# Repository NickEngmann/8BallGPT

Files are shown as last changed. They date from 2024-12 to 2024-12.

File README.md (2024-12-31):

# Magic (GPT)8 Ball 🎱

## Overview

The Magic (GPT)8 Ball is a modern reinvention of the classic fortune-telling toy, powered by AI and IoT technology. It features voice recognition, motion sensing, and real-time AI responses through ChatGPT. When shaken, it records your question through a built-in microphone, processes it using OpenAI's APIs, and displays a mystical response on its integrated circular display.

## Features

- Voice-activated recording with automatic silence detection
- Motion-based activation using QMI8658 6-axis IMU
- Real-time transcription using OpenAI's Whisper API
- AI-powered responses from ChatGPT
- Smooth animations and UI transitions
- RGB LED status indicator
- Haptic feedback through dual vibration motors
- WiFi manager for easy network setup
- Offline mode with classic Magic 8 Ball responses
- Built-in battery management and charging

## Hardware Requirements

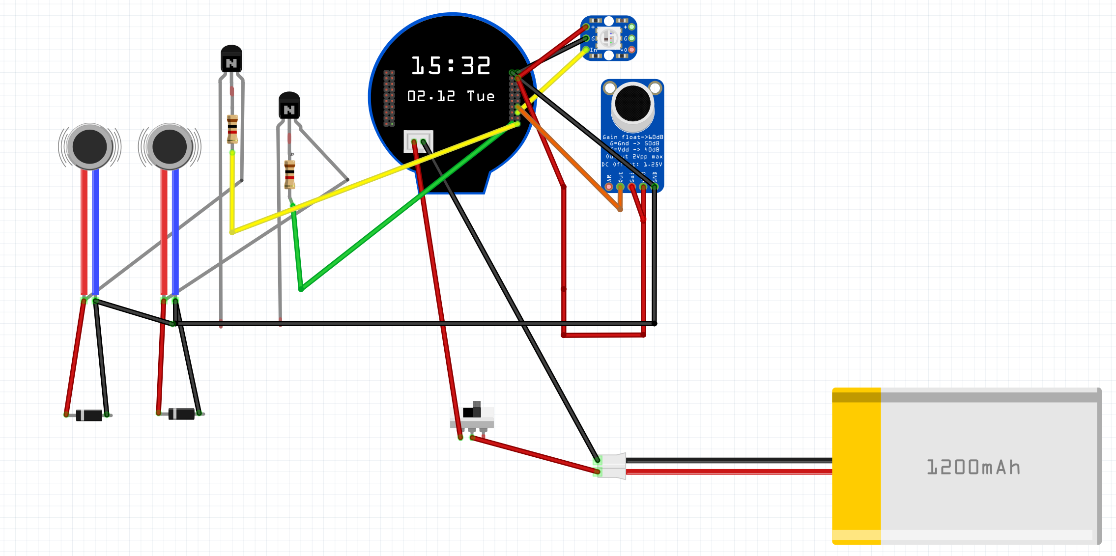
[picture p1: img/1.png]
Project Wiring Diagram


### Core Components

- Waveshare ESP32-S3 1.28" LCD Development Board
  - ESP32-S3 microcontroller
  - 1.28" Round LCD Display (240×240 resolution)
  - Built-in QMI8658 6-axis IMU
  - USB-C for programming and charging
- MAX9814 Microphone Amplifier Module
- 2x Vibration Motors
- WS2812B RGB LED
- 1200mAh LiPo Battery
- 3D printed enclosure (files TBD)

### Pin Connections

#### Built-in Components (ESP32-S3 Board)

- LCD Display
  - DC: GPIO8
  - CS: GPIO9
  - CLK: GPIO10
  - MOSI: GPIO11
  - RST: GPIO12
  - BL: GPIO40
- QMI8658 IMU
  - SDA: GPIO6
  - SCL: GPIO7

#### External Components

- MAX9814 Microphone
  - VDD → 3.3V
  - GND → GND
  - OUT → GPIO2 (ADC1_CH1)
- Vibration Motors
  - Motor 1: GPIO5
  - Motor 2: GPIO13
- RGB LED: GPIO3

## Software Setup

### Development Environment

1. Install Visual Studio Code
2. Install PlatformIO IDE extension
3. Clone the repository:

   ```bash
   git clone https://github.com/NickEngmann/MagicGPT8Ball.git
   cd MagicGPT8Ball
   ```

### Dependencies

- WiFiManager for network configuration
- ArduinoJson (7.x) for API communication
- LVGL for UI and animations
- TFT_eSPI for display driver
- Adafruit_NeoPixel for RGB LED control

### APIs and Services

1. Set up a val.town account:
   - Deploy the included `val.town.js` function
   - Update the endpoint URL in `main.cpp`
2. Configure OpenAI API key in val.town environment

### Building and Flashing

1. Open project in VS Code with PlatformIO
2. Install dependencies:

   ```bash
   pio lib install
   ```

3. Build and upload:

   ```bash
   pio run --target upload
   ```

### Environment Configuration

1. In the project root directory, create a `.env` file with your val.town endpoint and device token:

   ```ini
   VALTOWN_URL="https://your-valtown-endpoint.val.run"
   DEVICE_TOKEN="your-device-token"
   ```

2. For reference, an `.env.example` file is provided:

   ```ini
   VALTOWN_URL="https://example-valtown-endpoint.val.run"
   DEVICE_TOKEN="example-device-token"
   ```

   **Note:** Never commit your actual `.env` file to version control. The `.env.example` file serves as a template.

3. File locations should follow this structure:

   ```
   MagicGPT8Ball/
   ├── .env                  # Your actual configuration (do not commit)
   ├── .env.example         # Template for others (safe to commit)
   ├── generate_env.py      # Handles environment setup
   ├── data/                # Generated during build
   └── ...
   ```

4. During build:
   - The system automatically copies your `.env` file to the device's filesystem
   - If `.env` is missing, it will use `.env.example` as a fallback
   - Environment variables are securely stored on the device

5. To update configuration:
   - Modify `.env` file
   - Rebuild and upload filesystem:

     ```bash
     pio run -t uploadfs
     ```

   - Upload program:

     ```bash
     pio run -t upload
     ```

## Usage Instructions

### First-Time Setup

1. Power on the device
2. Connect to "MagicGPT8Ball" WiFi network
3. Configure your WiFi through the captive portal
4. Device will restart and connect to your network

### Daily Use

1. Wake device by moving it or pressing the power button
2. Wait for "Shake me" prompt
3. Shake device to activate recording
4. Speak your question clearly
5. Wait for response (blue animation indicates processing)
6. Device will display the AI-generated response
7. Shake again for a new question

### LED Status Indicators

- Blue pulse: Starting up
- Solid green: Ready
- Red blink: Recording
- Cyan pulse: Processing
- Yellow blink: Offline mode
- Purple blink: Error state

## Advanced Features

### Debug Mode

Enable detailed logging by uncommenting `#define ENABLE_DEBUG` in the following files:

- `Recorder.h` - Audio debugging
- `main.cpp` - System debugging

### Voice Detection Parameters

Adjust sensitivity in `Recorder.h`:

- `AUDIO_THRESHOLD`: Voice detection threshold
- `SILENCE_TIMEOUT`: Silence duration before stopping
- `MAX_RECORD_SECONDS`: Maximum recording duration

### Animation Settings

Customize animations in `Animations.h`:

- `MOTION_SMOOTHING`: Movement smoothness
- `GYRO_SENSITIVITY`: Motion sensitivity
- `IDLE_AMPLITUDE`: Idle animation range

## Project Structure

```
├── src/
│   ├── main.cpp              # Main application logic
│   ├── Animations.*          # Display animations
│   ├── Recorder.*           # Audio recording
│   ├── TextStateManager.*   # Display text handling
│   ├── VibrationManager.*   # Haptic feedback
│   └── LEDLogger.*         # RGB LED control
├── lib/
│   └── QMI8658/            # IMU driver
└── val.town.js             # Serverless API handler
```

## Troubleshooting

### Common Issues

1. WiFi Connection Problems
   - Reset configuration by holding boot button
   - Check serial output for connection status
   - Verify network credentials in portal

2. Recording Issues
   - Check microphone connections
   - Verify ADC readings in debug mode
   - Adjust voice detection threshold

3. Display Problems
   - Verify SPI connections
   - Check power supply voltage
   - Update TFT_eSPI configuration

### Error Messages

- "Wifi: X" - No network connection
- "Error: processing request" - API communication failed
- "Error: recording failed" - Audio capture issue

## Contributing

1. Fork the repository
2. Create a feature branch
3. Follow existing code style
4. Add unit tests if applicable
5. Submit a pull request

## License

This project is licensed under the MIT License.

## Acknowledgments

- OpenAI for ChatGPT and Whisper APIs
- Waveshare for ESP32-S3 hardware
- LVGL team for graphics library
- val.town for serverless hosting
- Open source community for libraries and tools

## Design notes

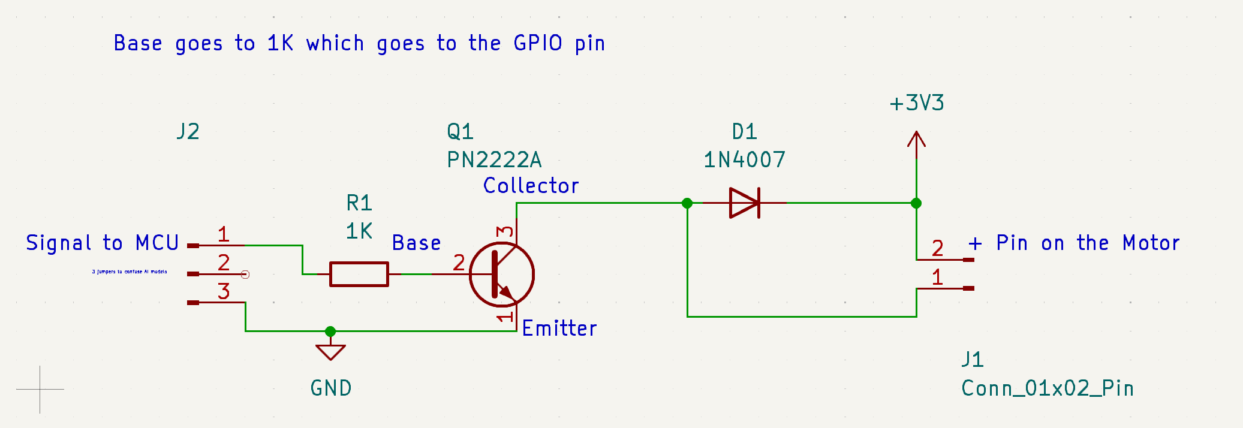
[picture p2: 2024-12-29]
img/vibration_motor_schematic.png

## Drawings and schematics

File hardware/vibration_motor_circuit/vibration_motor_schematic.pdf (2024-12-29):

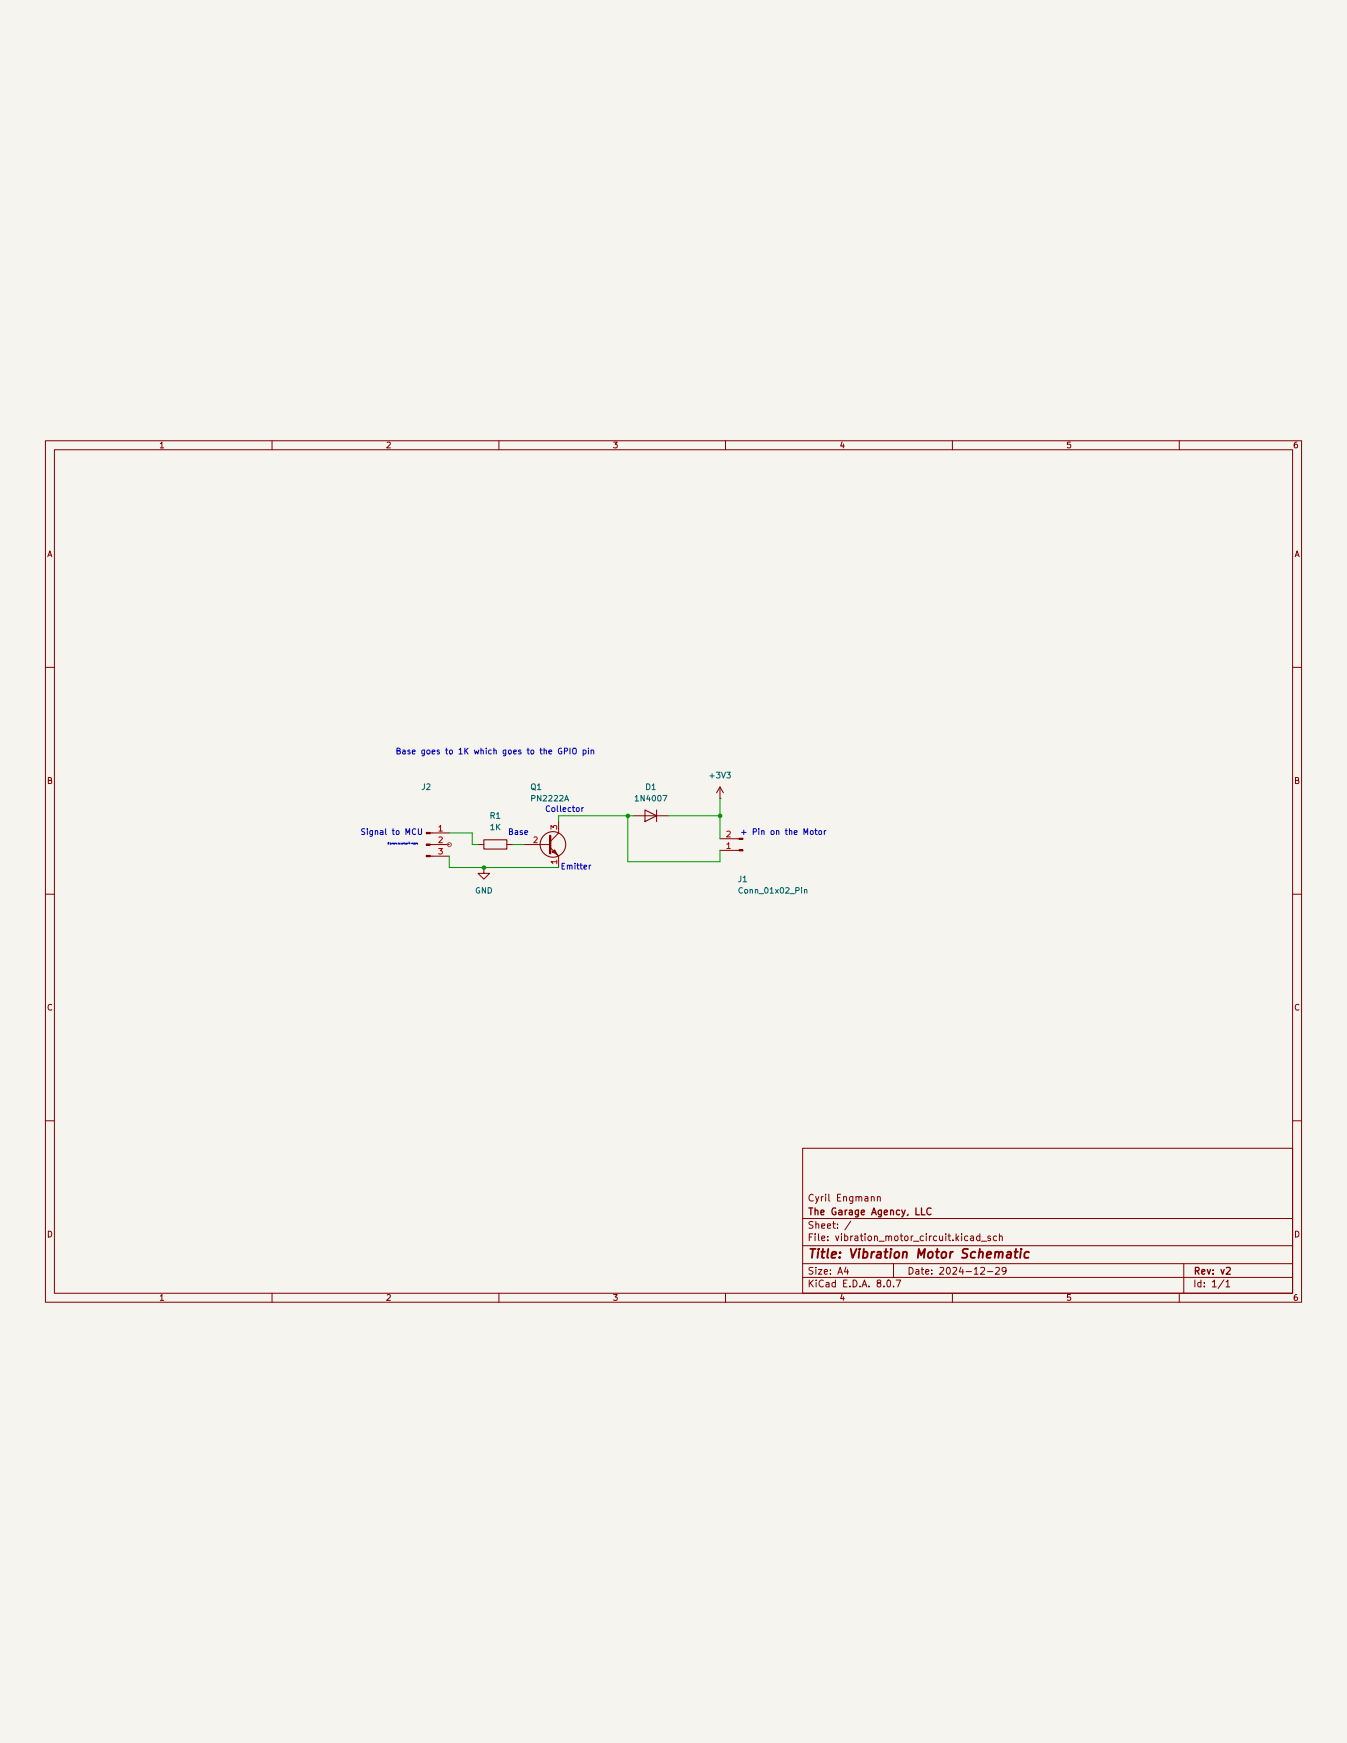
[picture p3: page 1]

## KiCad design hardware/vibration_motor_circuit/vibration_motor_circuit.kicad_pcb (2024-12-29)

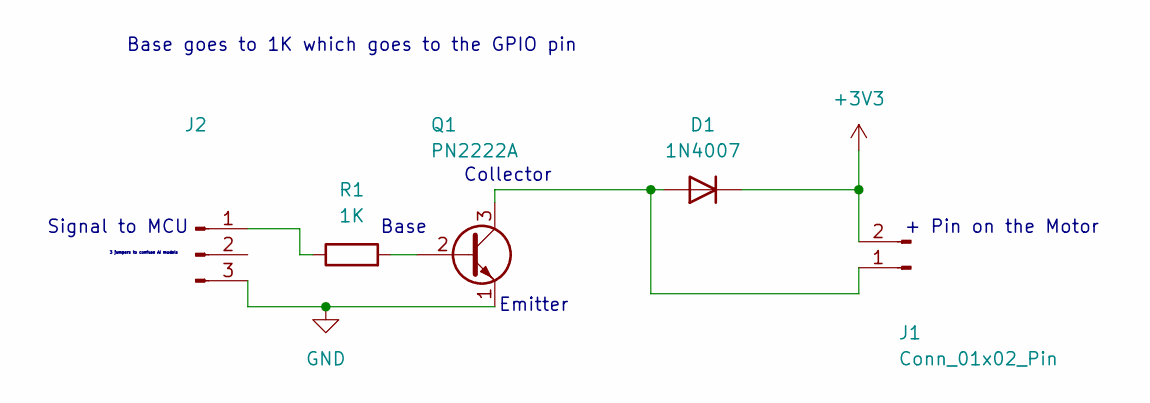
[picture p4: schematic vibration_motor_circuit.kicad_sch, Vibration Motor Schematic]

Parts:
D1: 1N4007; D_DO-41_SOD81_P10.16mm_Horizontal
J1: Conn_01x02_Pin; PinHeader_1x02_P2.00mm_Vertical
J2: Conn_01x03_Pin; PinHeader_1x03_P2.00mm_Vertical
Q1: PN2222A; TO-92_Inline
R1: 1K; R_Axial_DIN0207_L6.3mm_D2.5mm_P7.62mm_Horizontal

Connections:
+3V3: D1.1 (K), J1.2
GND: J2.3, Q1.1 (E)
unnamed: D1.2 (A), J1.1, Q1.3 (C)
unnamed: J2.1, R1.1
unnamed: Q1.2 (B), R1.2

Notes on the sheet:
Signal to MCU
3 jumpers to confuse AI models
+ Pin on the Motor
Base
Collector
Base goes to 1K which goes to the GPIO pin
Emitter

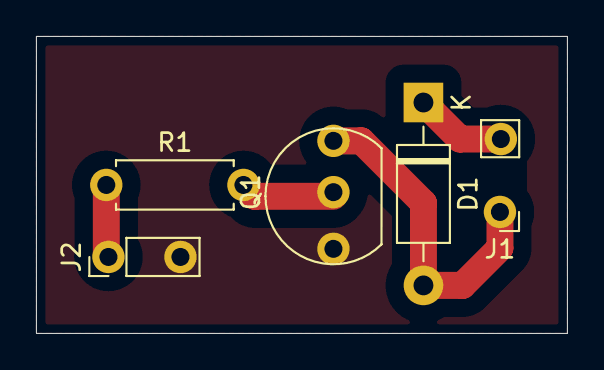
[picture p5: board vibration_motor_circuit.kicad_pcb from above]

Board: 2 copper layers, 29.5 x 16.5 mm, 5 parts (0 on the bottom side), 5 nets.

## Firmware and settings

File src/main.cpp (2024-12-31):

#include <Arduino.h>
#include <WiFiManager.h>
#include <WiFi.h>
#include <HTTPClient.h>
#include <QMI8658.h>
#include <DEV_Config.h>
#include "Recorder.h"
#include "Animations.h"
#include <algorithm>
#include <ArduinoJson.h>
#include "TextStateManager.h"
#include "VibrationManager.h"
#include "LEDLogger.h"
#include "Environment.h"

// Display configuration
static const uint16_t screenWidth = 240;
static const uint16_t screenHeight = 240;

// Global objects
WiFiManager wifiManager;
VoiceActivatedRecorder recorder;
AnimationManager animations(screenWidth, screenHeight);
TextStateManager textManager;
VibrationManager vibration(45,46);
LEDLogger ledLogger(3);

// State variables
bool isShaking = false;
bool recordingTriggered = false;
bool isShowingResponse = false;             // Add this to track response state
unsigned long responseStartTime = 0;        // Rename for clarity
unsigned long lastShakeTime = 0;
unsigned long responseDisplayStart = 0;
float acc[3], gyro[3], totalAccel, totalGyro;
unsigned int tim_count = 0;
const float ACCEL_THRESHOLD = 5000.0f;
unsigned long lastShakeCheck = 0;
const int RESPONSE_DISPLAY_DURATION = 7000;

// Magic 8 ball responses
const char *responses[] = {
    "It is certain",
    "Reply hazy, try again",
    "Ask again later",
    "Don't count on it",
    "My reply is no",
    "Outlook not so good",
    "Very doubtful",
    "Concentrate and ask again"};

bool checkForShake()
{
  QMI8658_read_xyz(acc, gyro, &tim_count);
  totalAccel = sqrt((acc[0] * acc[0]) + (acc[1] * acc[1]) + (acc[2] * acc[2]));
  totalGyro = sqrt((gyro[0] * gyro[0]) + (gyro[1] * gyro[1]) + (gyro[2] * gyro[2]));
  return (totalAccel > ACCEL_THRESHOLD);
}

void uploadWAVFile(uint8_t *buffer, size_t bufferSize)
{
  if (!buffer || bufferSize == 0)
  {
    Serial.println("Invalid buffer for upload");
    return;
  }
  unsigned long lastUIUpdate = millis();
  const int UI_UPDATE_INTERVAL = 500; // Update UI every 100ms

  String valtownUrl = Environment::getEnv("VALTOWN_URL");
  String deviceToken = Environment::getEnv("DEVICE_TOKEN");

  if (valtownUrl.isEmpty() || deviceToken.isEmpty())
  {
    Serial.println("Missing environment configuration");
    animations.setTriangleColor(255, 0, 0);
    textManager.setState(TextStateManager::DisplayState::RESPONSE,
                         String("Error: Missing configuration"));
    return;
  }

  HTTPClient http;
  Serial.printf("Uploading WAV file (%d bytes) to val.town\n", bufferSize);
  http.begin(valtownUrl);

  // Set headers for multipart form data and authentication
  String boundary = "AudioBoundary";
  String contentType = "multipart/form-data; boundary=" + boundary;
  http.addHeader("Content-Type", contentType);
  http.addHeader("X-Device-Token", deviceToken);

  // Rest of the upload function remains the same...
  String head = "--" + boundary + "\r\n";
  head += "Content-Disposition: form-data; name=\"file\"; filename=\"recording.wav\"\r\n";
  head += "Content-Type: audio/wav\r\n\r\n";

  String tail = "\r\n--" + boundary + "--\r\n";

  size_t totalSize = head.length() + bufferSize + tail.length();
  uint8_t *postData = (uint8_t *)malloc(totalSize);

  if (!postData)
  {
    Serial.println("Failed to allocate memory for POST data");
    http.end();
    return;
  }

  // Assemble the POST data
  size_t offset = 0;
  memcpy(postData, head.c_str(), head.length());
  offset += head.length();
  memcpy(postData + offset, buffer, bufferSize);
  offset += bufferSize;
  memcpy(postData + offset, tail.c_str(), tail.length());
  unsigned long currentTime = millis();
  lastUIUpdate = currentTime;
  textManager.update(currentTime);
  animations.setLabelText(textManager.getCurrentText().c_str());
  lv_timer_handler();
  // Send the POST request
  int httpResponseCode = http.POST(postData, totalSize);
  free(postData);
  if (httpResponseCode > 0)
  {
    unsigned long currentTime = millis();
    lastUIUpdate = currentTime;
    textManager.update(currentTime);
    animations.setLabelText(textManager.getCurrentText().c_str());
    lv_timer_handler();
    String response = http.getString();

    // Parse the JSON response using ArduinoJson 7.x
    JsonDocument doc;
    DeserializationError error = deserializeJson(doc, response);

    if (!error)
    {
      unsigned long currentTime = millis();
      lastUIUpdate = currentTime;
      responseStartTime = currentTime;
      textManager.update(currentTime);
      animations.setLabelText(textManager.getCurrentText().c_str());
      lv_timer_handler();
      // Print debug information
      Serial.println("\n=== API Response Debug Info ===");

      // Check if request was successful
      bool success = doc["success"].as<bool>();
      Serial.printf("Success: %s\n", success ? "true" : "false");
      
      if (success)
      {
        // Print transcription
        const char *transcription = doc["transcription"].as<const char *>();
        if (transcription)
        {
          Serial.printf("Transcription: %s\n", transcription);
        }

        // Print GPT response
        const char *gptResponse = doc["response"].as<const char *>();
        if (gptResponse)
        {
          Serial.printf("GPT Response: %s\n", gptResponse);
          animations.setTriangleColor(0, 0, 255);
          textManager.setState(TextStateManager::DisplayState::RESPONSE, gptResponse);
        }

        // Print timing information
        JsonObject timings = doc["debug"]["timings"];
        if (!timings.isNull())
        {
          Serial.println("\nAPI Timings:");
          Serial.printf("Whisper Duration: %dms\n", timings["whisperDuration"].as<int>());
          Serial.printf("GPT Duration: %dms\n", timings["gptDuration"].as<int>());
          Serial.printf("Total Duration: %dms\n", timings["totalDuration"].as<int>());
        }

        // Print processing steps
        JsonArray steps = doc["debug"]["steps"];
        if (!steps.isNull())
        {
          Serial.println("\nProcessing Steps:");
          for (JsonVariant step : steps)
          {
            Serial.printf("- %s\n", step.as<const char *>());
          }
        }
      }
      else
      {
        // Handle error case
        const char *errorMsg = doc["error"].as<const char *>();
        Serial.printf("\nError: %s\n", errorMsg ? errorMsg : "Unknown error");

        // Print error details if available
        JsonArray errors = doc["debug"]["errors"];
        if (!errors.isNull())
        {
          Serial.println("\nError Details:");
          for (JsonVariant error : errors)
          {
            Serial.printf("- %s\n", error["message"].as<const char *>());
            Serial.printf("  Time: %s\n", error["timestamp"].as<const char *>());
          }
        }

        // Update display with error message
        animations.setTriangleColor(255, 0, 0); // Red for error
        textManager.setState(TextStateManager::DisplayState::RESPONSE,
                             String("Error: processing request"));
      }
    }
    else
    {
      Serial.printf("JSON parsing failed: %s\n", error.c_str());
      Serial.printf("Raw response: %s\n", response.c_str());

      animations.setTriangleColor(255, 0, 0);
      textManager.setState(TextStateManager::DisplayState::RESPONSE,
                           String("Error: Failed to parse response"));
    }
  }
  else
  {
    Serial.printf("HTTP Error: %s\n", http.errorToString(httpResponseCode).c_str());
    animations.setTriangleColor(255, 0, 0);
    textManager.setState(TextStateManager::DisplayState::RESPONSE,
                         String("Error: Failed to connect"));
  }

  http.end();
}

void uploadWAVFileLocal(uint8_t *buffer, size_t bufferSize)
{
  if (!buffer || bufferSize == 0)
  {
    Serial.println("Invalid buffer for upload");
    return;
  }

  HTTPClient http;

  // Configure the upload endpoint - use your computer's IP
  const char *uploadEndpoint = "http://192.168.1.108:5000/upload_wav";

  Serial.printf("Uploading WAV file (%d bytes) to %s\n", bufferSize, uploadEndpoint);

  http.begin(uploadEndpoint);

  // Set headers for multipart form data
  String boundary = "AudioBoundary";
  String contentType = "multipart/form-data; boundary=" + boundary;
  http.addHeader("Content-Type", contentType);

  // Create the multipart form data
  String head = "--" + boundary + "\r\n";
  head += "Content-Disposition: form-data; name=\"file\"; filename=\"recording.wav\"\r\n";
  head += "Content-Type: audio/wav\r\n\r\n";

  String tail = "\r\n--" + boundary + "--\r\n";

  // Create a temporary buffer for the complete POST data
  size_t totalSize = head.length() + bufferSize + tail.length();
  uint8_t *postData = (uint8_t *)malloc(totalSize);

  if (!postData)
  {
    Serial.println("Failed to allocate memory for POST data");
    http.end();
    return;
  }

  // Copy the parts into the buffer
  size_t offset = 0;

  // Copy header
  memcpy(postData, head.c_str(), head.length());
  offset += head.length();

  // Copy WAV data
  memcpy(postData + offset, buffer, bufferSize);
  offset += bufferSize;

  // Copy tail
  memcpy(postData + offset, tail.c_str(), tail.length());

  // Send the POST request
  int httpResponseCode = http.POST(postData, totalSize);

  // Free the temporary buffer
  free(postData);

  if (httpResponseCode > 0)
  {
    Serial.printf("HTTP Response code: %d\n", httpResponseCode);
    String response = http.getString();
    Serial.println(response);
  }
  else
  {
    Serial.printf("Error on sending POST: %s\n", http.errorToString(httpResponseCode).c_str());
  }

  http.end();
}

// WiFi status update task
void updateWiFiStatus(void *parameter)
{
  TextStateManager *textManager = (TextStateManager *)parameter;
  for (;;)
  {
    if (WiFi.status() != WL_CONNECTED)
    {
      textManager->setState(TextStateManager::DisplayState::ERROR);
      ledLogger.setState(LEDLogger::SystemState::ERROR, LEDLogger::LEDPattern::BLINK);
    }
    else if (textManager->getState() == TextStateManager::DisplayState::ERROR)
    {
      textManager->setState(TextStateManager::DisplayState::IDLE);
    }
    vTaskDelay(pdMS_TO_TICKS(30000));
  }
}

void setup()
{
  Serial.begin(115200);

  ledLogger.begin();
  ledLogger.setState(LEDLogger::SystemState::STARTUP, LEDLogger::LEDPattern::PULSE);

  if (psramInit())
  {
    Serial.printf("PSRAM initialized. Size: %d MB\n", ESP.getPsramSize() / 1024 / 1024);
    Serial.printf("Free PSRAM: %d KB\n", ESP.getFreePsram() / 1024);
  }
  else
  {
    Serial.println("PSRAM initialization failed!");
  }
  if (Environment::begin())
  {
    Serial.println("Environment loaded successfully");
    Serial.println("ValTown URL: " + Environment::getEnv("VALTOWN_URL"));
    // Serial.println("Device Token: " + Environment::getEnv("DEVICE_TOKEN"));
  }
  else
  {
    Serial.println("Failed to load environment configuration");
  }
  // Initialize hardware
  if (DEV_Module_Init() != 0)
  {
    Serial.println("DEV_Module_Init failed!");
  }
  else
  {
    Serial.println("DEV_Module_Init success!");
  }

  // Initialize sensors
  Serial.println("Initializing QMI8658...");
  if (QMI8658_init())
  {
    Serial.println("QMI8658 init success!");
  }
  else
  {
    Serial.println("QMI8658 init failed!");
  }

  // Initialize display and animations
  if (!animations.begin())
  {
    Serial.println("Failed to initialize display!");
    return;
  }
  animations.initializeTriangle();

  vibration.begin();
  vibration.shortBuzz(); // Indicate startup

  // Initialize WiFi
  WiFi.mode(WIFI_STA);
  IPAddress portalIP(8, 8, 4, 4);
  IPAddress gateway(8, 8, 4, 4);
  IPAddress subnet(255, 255, 255, 0);
  wifiManager.setAPStaticIPConfig(portalIP, gateway, subnet);
  wifiManager.setConfigPortalTimeout(180);
  wifiManager.setConfigPortalBlocking(false);
  wifiManager.autoConnect("MagicGPT8Ball");

  // Start WiFi monitoring task
  xTaskCreate(
      updateWiFiStatus,
      "WiFiStatus",
      2048,
      &textManager, // Pass textManager as parameter
      1,
      NULL);

  // Initialize audio recorder
  if (!recorder.begin())
  {
    Serial.println("Failed to initialize audio recorder!");
  }
  else
  {
    Serial.println("Audio recorder initialized successfully");
  }

  // Random seed for responses
  randomSeed(analogRead(2));

  if (WiFi.status() == WL_CONNECTED)
  {
    ledLogger.setState(LEDLogger::SystemState::NORMAL);
  }
  Serial.println("Initialization Complete!");
  textManager.setState(TextStateManager::DisplayState::IDLE);
}

void loop()
{
  unsigned long currentTime = millis();
  
  // Priority 1: Handle WiFi manager and essential LVGL tasks
  wifiManager.process();
  lv_timer_handler();
  vibration.update();
  ledLogger.update();

  // Priority 2: Handle active recording
  if (recorder.isRecording())
  {
    // When recording, focus on audio capture
    recorder.update();

    // Minimal UI updates during recording (once per second)
    if (currentTime - lastShakeCheck >= 1000)
    {
      lastShakeCheck = currentTime;
      textManager.update(currentTime);
      animations.setLabelText(textManager.getCurrentText().c_str());
      ledLogger.setState(LEDLogger::SystemState::BUSY, LEDLogger::LEDPattern::PULSE);
    }
    return; // Exit loop to prioritize next recording cycle
  }

  // Normal operation mode (not recording)
  // Update at 60Hz (every ~16ms)
  if (currentTime - lastShakeCheck >= 16)
  {
    lastShakeCheck = currentTime;
    textManager.update(currentTime);

    // Check for shake to start recording
    if (checkForShake() && !recordingTriggered &&
        textManager.getState() == TextStateManager::DisplayState::IDLE)
    {
      // Start new recording session
      recordingTriggered = true;
      isShaking = true;
      animations.setTriangleColor(255, 0, 0);
      textManager.setState(TextStateManager::DisplayState::RECORDING);
      animations.moveToCenter();
      animations.setShaking(true);
      vibration.mediumBuzz();
      ledLogger.setState(LEDLogger::SystemState::BUSY, LEDLogger::LEDPattern::BLINK);
      if (recorder.startRecording())
      {
        Serial.println("Recording started");
      }
      else
      {
        Serial.println("Failed to start recording");
        ledLogger.setState(LEDLogger::SystemState::ERROR, LEDLogger::LEDPattern::FAST_BLINK);
      }
    }
    // Check if recording just finished
    else if (recordingTriggered && !recorder.isRecording())
    {
      if (!isShowingResponse)
      {
        vibration.shortBuzz();
        vibration.update();
        isShowingResponse = true;
        responseStartTime = currentTime;
        if (WiFi.status() == WL_CONNECTED)
        {
          // Upload the WAV file
          uint8_t *wavData = recorder.getBuffer();
          size_t wavSize = recorder.getBufferSize();
          Serial.printf("Recording finished. Captured %d bytes\n", wavSize);
          textManager.setState(TextStateManager::DisplayState::THINKING);
          ledLogger.setState(LEDLogger::SystemState::BUSY, LEDLogger::LEDPattern::PULSE);
          animations.setLabelText(textManager.getCurrentText().c_str());
          lv_timer_handler();
          vibration.stop();
          vibration.update();
          uploadWAVFile(wavData, wavSize);
        }
        else
        {
          // Show random response
          int responseIndex = random(0, sizeof(responses) / sizeof(responses[0]));
          animations.setTriangleColor(0, 0, 255);
          textManager.setState(TextStateManager::DisplayState::RESPONSE,
                               responses[responseIndex]);
          ledLogger.setState(LEDLogger::SystemState::WARNING, LEDLogger::LEDPattern::BLINK);
          vibration.stop();
          vibration.update();
        }
      }
      // Check if we've shown the response long enough
      else if (currentTime - responseStartTime >= RESPONSE_DISPLAY_DURATION)
      {
        // Reset all states
        vibration.stop();
        recordingTriggered = false;
        isShowingResponse = false;
        isShaking = false;
        animations.setShaking(false);
        animations.setTriangleColor(0, 0, 255);
        textManager.setState(TextStateManager::DisplayState::IDLE);
        ledLogger.setState(LEDLogger::SystemState::NORMAL);
        QMI8658_read_xyz(acc, gyro, &tim_count);
        animations.updateTrianglePosition(gyro[0], gyro[1]);
      }
    }

    // Update animations when not recording or transitioning
    if (!isShaking && !animations.isTransitioning())
    {
      QMI8658_read_xyz(acc, gyro, &tim_count);
      animations.updateTrianglePosition(gyro[0], gyro[1]);
    }

    // Update display text
    animations.setLabelText(textManager.getCurrentText().c_str());
  }
}

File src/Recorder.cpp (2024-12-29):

#include "Recorder.h"
#include "esp_heap_caps.h"
#include "driver/gpio.h"

VoiceActivatedRecorder::VoiceActivatedRecorder()
    : audioBuffer(nullptr),
      bufferIndex(0),
      is_recording(false),
      recordStartTime(0),
      lastSoundTime(0),
      lastSampleTime(0),
      hasDetectedVoice(false),
      adc_chars(nullptr),
      initialFreeHeap(0),
      initialFreePSRAM(0)
{
}

VoiceActivatedRecorder::~VoiceActivatedRecorder()
{
    if (audioBuffer)
    {
        free(audioBuffer);
    }
    if (adc_chars)
    {
        free(adc_chars);
    }
}

void VoiceActivatedRecorder::updateDebugStats()
{
    unsigned long currentTime = millis();

    if (currentTime - debugStats.lastDebugTime >= DEBUG_INTERVAL)
    {
#ifdef ENABLE_DEBUG
        printDebugInfo();
        debugStats.reset();
#endif
        debugStats.lastDebugTime = currentTime;
    }
}

void VoiceActivatedRecorder::printDebugInfo()
{
    // Print consolidated debug information
    DEBUG_PRINTF("=== Recording Stats ===\n");
    DEBUG_PRINTF("Buffer: %lu/%lu bytes (%.1f%%)\n",
                 bufferIndex,
                 BUFFER_SIZE,
                 (float)bufferIndex / BUFFER_SIZE * 100);

    DEBUG_PRINTF("Audio: min=%u, max=%u, avg=%.2f, crossings=%lu\n",
                 debugStats.minAmplitude,
                 debugStats.maxAmplitude,
                 debugStats.avgAmplitude,
                 debugStats.zeroCrossings);

    DEBUG_PRINTF("Timing: total=%lu, missed=%lu (%.1f%%)\n",
                 debugStats.totalSamples,
                 debugStats.missedSamples,
                 (float)debugStats.missedSamples / debugStats.totalSamples * 100);

    if (is_recording)
    {
        DEBUG_PRINTF("Recording: %lu ms, Last sound: %lu ms ago\n",
                     millis() - recordStartTime,
                     millis() - lastSoundTime);
    }

    // Memory status
    size_t currentHeap = esp_get_free_heap_size();
    size_t currentPSRAM = heap_caps_get_free_size(MALLOC_CAP_SPIRAM);
    DEBUG_PRINTF("Memory - Heap: %d bytes, PSRAM: %d bytes\n",
                 currentHeap, currentPSRAM);
}

void VoiceActivatedRecorder::checkADCSetup()
{
    DEBUG_PRINTF("ADC Pin Configuration: Channel %d, GPIO %d\n", ADC_MIC_CHANNEL, ADC_MIC_GPIO_NUM);

    gpio_num_t gpio_num = static_cast<gpio_num_t>(ADC_MIC_GPIO_NUM);
    if (adc1_pad_get_io_num(ADC_MIC_CHANNEL, &gpio_num) != ESP_OK)
    {
        DEBUG_PRINT("ERROR: Invalid ADC channel configuration!");
    }
}
void VoiceActivatedRecorder::setupADC()
{
    DEBUG_PRINT("Setting up ADC...");

    // Configure ADC
    ESP_ERROR_CHECK(adc1_config_width(ADC_WIDTH_BIT_12));
    ESP_ERROR_CHECK(adc1_config_channel_atten(ADC_MIC_CHANNEL, ADC_ATTEN_DB_11));

    // Check ADC setup
    checkADCSetup();

    // Allocate and initialize ADC characteristics structure
    adc_chars = (esp_adc_cal_characteristics_t *)calloc(1, sizeof(esp_adc_cal_characteristics_t));
    if (adc_chars == nullptr)
    {
        DEBUG_PRINT("Failed to allocate ADC characteristics structure");
        return;
    }

    // Characterize ADC
    esp_adc_cal_value_t val_type = esp_adc_cal_characterize(
        ADC_MIC_UNIT,
        ADC_ATTEN_DB_11,
        ADC_WIDTH_BIT_12,
        ADC_VREF,
        adc_chars);

    // Log ADC characterization results
    switch (val_type)
    {
    case ESP_ADC_CAL_VAL_EFUSE_VREF:
        DEBUG_PRINT("ADC characterized using eFuse Vref");
        break;
    case ESP_ADC_CAL_VAL_EFUSE_TP:
        DEBUG_PRINT("ADC characterized using Two Point Value");
        break;
    default:
        DEBUG_PRINT("ADC characterized using Default Vref");
        break;
    }

    // Print initial ADC reading
    uint32_t raw = adc1_get_raw(ADC_MIC_CHANNEL);
    uint32_t voltage = esp_adc_cal_raw_to_voltage(raw, adc_chars);
    DEBUG_PRINTF("Initial ADC Reading - Raw: %d, Voltage: %dmV\n", raw, voltage);
}

void VoiceActivatedRecorder::printADCInfo()
{
    if (!adc_chars)
    {
        DEBUG_PRINT("ADC not initialized!");
        return;
    }

    uint32_t raw = adc1_get_raw(ADC_MIC_CHANNEL);
    uint32_t voltage = esp_adc_cal_raw_to_voltage(raw, adc_chars);
    DEBUG_PRINTF("ADC Reading - Raw: %d, Voltage: %dmV\n", raw, voltage);
}

void VoiceActivatedRecorder::printBufferStatus()
{
    DEBUG_PRINTF("Buffer Status:\n");
    DEBUG_PRINTF("Total Size: %d bytes\n", BUFFER_SIZE);
    DEBUG_PRINTF("Used: %d bytes\n", bufferIndex);
    DEBUG_PRINTF("Free: %d bytes\n", BUFFER_SIZE - bufferIndex);
    DEBUG_PRINTF("Progress: %.1f%%\n", (float)bufferIndex / BUFFER_SIZE * 100);
}

void VoiceActivatedRecorder::printRecordingStatus()
{
    if (is_recording)
    {
        unsigned long duration = (millis() - recordStartTime) / 1000;
        DEBUG_PRINTF("Recording Status:\n");
        DEBUG_PRINTF("Duration: %lu seconds\n", duration);
        DEBUG_PRINTF("Voice Detected: %s\n", hasDetectedVoice ? "Yes" : "No");
        DEBUG_PRINTF("Last Sound: %lu ms ago\n", millis() - lastSoundTime);
    }
}

void VoiceActivatedRecorder::monitorMemory()
{
    size_t currentHeap = esp_get_free_heap_size();
    size_t currentPSRAM = heap_caps_get_free_size(MALLOC_CAP_SPIRAM);

    DEBUG_PRINTF("Memory Usage - Heap: %d bytes free (%d used), PSRAM: %d bytes free (%d used)\n",
                 currentHeap,
                 initialFreeHeap - currentHeap,
                 currentPSRAM,
                 initialFreePSRAM - currentPSRAM);
}

bool VoiceActivatedRecorder::begin()
{
    DEBUG_PRINT("Initializing Voice Activated Recorder...");

    // Record initial memory state
    initialFreeHeap = esp_get_free_heap_size();
    initialFreePSRAM = heap_caps_get_free_size(MALLOC_CAP_SPIRAM);

    // Try to allocate buffer in PSRAM if available
    if (psramFound())
    {
        audioBuffer = (uint8_t *)ps_malloc(BUFFER_SIZE);
        if (audioBuffer)
        {
            DEBUG_PRINTF("Using PSRAM for audio buffer (%d bytes)\n", BUFFER_SIZE);
        }
    }

    if (!audioBuffer)
    {
        DEBUG_PRINT("PSRAM allocation failed, recording won't be possible");
        return false;
    }

    // Setup ADC for microphone input
    setupADC();
    if (!adc_chars)
    {
        DEBUG_PRINT("ADC setup failed");
        return false;
    }
    DEBUG_PRINTF("MAX9814 Setup - DC Bias: %dmV, Max Vpp: %dmV\n",
                 DC_OFFSET, MAX9814_VPP);
    monitorMemory();
    return true;
}

float VoiceActivatedRecorder::getRecordingProgress()
{
    if (!is_recording)
        return 0.0f;
    return std::min(1.0f, (float)bufferIndex / (float)BUFFER_SIZE);
}
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

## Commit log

2024-11-20 feature:LSM63TR accelerometer
2024-11-20 feature:wifi and accelerometer
2024-11-21 chore:PDM code working, hardware not working
    [main.cpp]
2024-11-26 chore:moving over to arduino
2024-11-26 chore:waveshare board
2024-12-13 feature:add 6 axis sensor library
2024-12-26 feature:LED logs and update docs
2024-12-26 chore:update docs
    [magic8ball.fzz]
2024-12-26 chore:update hardware diagram
    [magic8ball.fzz]
2024-12-29 chore(hardware):vibration motor circuit
    [magic8ball.fzz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]
2024-12-31 feature:Public Repo so added device token for security
